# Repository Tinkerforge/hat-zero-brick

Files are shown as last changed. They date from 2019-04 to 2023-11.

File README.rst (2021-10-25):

HAT Zero Brick
==============

This repository contains the firmware source code and the hardware design
files. The documentation generator configs can be found at
https://github.com/Tinkerforge/generators

Repository Content
------------------

software/:
 * examples/: Examples for all supported languages
 * build/: Compiled files
 * src/: Source code of firmware
 * Makefile: Makefile to build project

hardware/:
 * Contains KiCad project files and additionally schematics as PDF

datasheets/:
 * Contains datasheets for sensors and complex ICs that are used

Hardware
--------

The hardware is designed with the open source EDA Suite KiCad
(http://www.kicad.org). Before you are able to open the files,
you have to install the Tinkerforge kicad-libraries
(https://github.com/Tinkerforge/kicad-libraries). You can either clone
them directly in hardware/ or clone them in a separate folder and
symlink them into hardware/
(ln -s kicad_path/kicad-libraries project_path/hardware). After that you
can open the .pro file in hardware/ with KiCad and from there view and
modify the schematics and the PCB layout.

Software
--------

If you want to do your own Brick/Bricklet firmware development we highly
recommend that you use our build environment setup script and read the
tutorial (https://www.tinkerforge.com/en/doc/Tutorials/Tutorial_Build_Environment/Tutorial.html).

To compile the C code we recommend you to install the newest GNU Arm Embedded
Toolchain (https://launchpad.net/gcc-arm-embedded/+download).
You also need to install bricklib2 (https://github.com/Tinkerforge/bricklib2).

You can either clone it directly in software/src/ or clone it in a
separate folder and symlink it into software/src/
(ln -s bricklib_path/bricklib2 project_path/software/src/). Finally make sure to
have CMake installed (http://www.cmake.org/cmake/resources/software.html).

After that you can build the firmware by invoking make in software/.
The firmware (.zbin) can then be found in software/build/ and uploaded
with brickv (click button "Flashing" on start screen).

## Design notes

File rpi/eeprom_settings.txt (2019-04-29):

########################################################################
# EEPROM settings text file
#
# Edit this file for your particular board and run through eepmake tool,
# then use eepflash tool to write to attached HAT ID EEPROM 
#
# Tools available:
#  eepmake   Parses EEPROM text file and creates binary .eep file
#  eepdump   Dumps a binary .eep file as human readable text (for debug)
#  eepflash  Write or read .eep binary image to/from HAT EEPROM
#
########################################################################

########################################################################
# Vendor info

# 128 bit UUID. If left at zero eepmake tool will auto-generate
# RFC 4122 compliant UUID
product_uuid b7603365-412f-47ef-a4d2-e60170d12fc1

# 16 bit product id (2126)
product_id 0x085D

# 16 bit product version
product_ver 0x001

# ASCII vendor string  (max 255 characters)
vendor "Tinkerforge GmbH"

# ASCII product string (max 255 characters)
product "HAT Zero Brick"

########################################################################
# GPIO bank settings, set to nonzero to change from the default.
# NOTE these setting can only be set per BANK, uncommenting any of
# these will force the bank to use the custom setting.

# drive strength, 0=default, 1-8=2,4,6,8,10,12,14,16mA, 9-15=reserved
gpio_drive 0

# 0=default, 1=slew rate limiting, 2=no slew limiting, 3=reserved
gpio_slew 0

# 0=default, 1=hysteresis disabled, 2=hysteresis enabled, 3=reserved
gpio_hysteresis 0

# If board back-powers Pi via 5V GPIO header pins:
# 0 = board does not back-power
# 1 = board back-powers and can supply the Pi with a minimum of 1.3A
# 2 = board back-powers and can supply the Pi with a minimum of 2A
# 3 = reserved
# If back_power=2 then USB high current mode will be automatically 
# enabled on the Pi
back_power 1

########################################################################
# GPIO pins, uncomment for GPIOs used on board
# Options for FUNCTION: INPUT, OUTPUT, ALT0-ALT5
# Options for PULL: DEFAULT, UP, DOWN, NONE
# NB GPIO0 and GPIO1 are reserved for ID EEPROM so cannot be set

#         GPIO  FUNCTION  PULL
#         ----  --------  ----
#setgpio  2     INPUT     DEFAULT
#setgpio  3     INPUT     DEFAULT
#setgpio  4     INPUT     DEFAULT
#setgpio  5     INPUT     DEFAULT
#setgpio  6     INPUT     DEFAULT
#setgpio  7     INPUT     DEFAULT
#setgpio  8     INPUT     DEFAULT
#setgpio  9     INPUT     DEFAULT
#setgpio  10    INPUT     DEFAULT
#setgpio  11    INPUT     DEFAULT
#setgpio  12    INPUT     DEFAULT
#setgpio  13    INPUT     DEFAULT
#setgpio  14    INPUT     DEFAULT
#setgpio  15    INPUT     DEFAULT
#setgpio  16    INPUT     DEFAULT
#setgpio  17    INPUT     DEFAULT
#setgpio  18    INPUT     DEFAULT
#setgpio  19    INPUT     DEFAULT
#setgpio  20    INPUT     DEFAULT
#setgpio  21    INPUT     DEFAULT
setgpio  22    OUTPUT     UP           # Chip Select
setgpio  23    OUTPUT     UP           # Chip Select
setgpio  24    OUTPUT     UP           # Chip Select
setgpio  25    OUTPUT     UP           # Chip Select
#setgpio  26    INPUT     DEFAULT
setgpio  27    OUTPUT     UP           # Chip Select

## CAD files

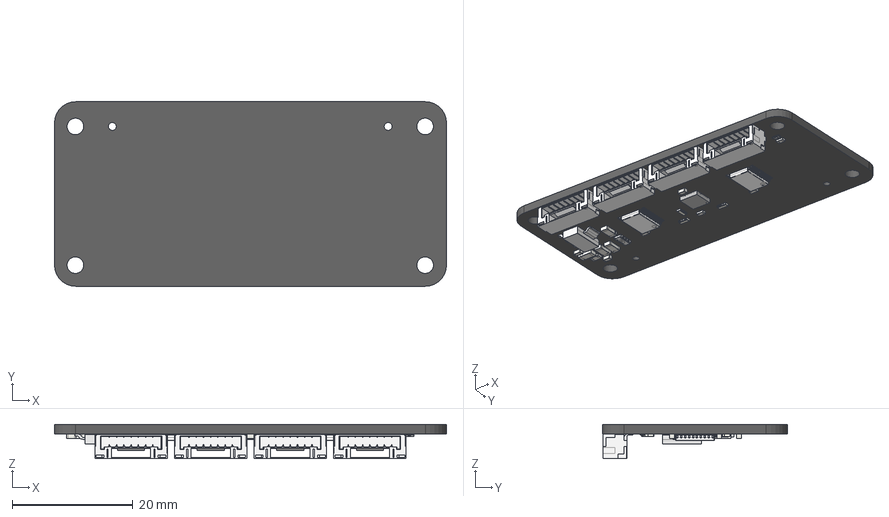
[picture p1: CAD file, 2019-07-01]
hardware/hat-zero.FCStd
65.0 x 30.6 x 5.70 mm
Pcb
U202_TSSOP-20_5B6C4061
CP203_Cut_5B6C3E7D
C101_C_0603_5C90B1AD
C102_C_1206_5B6C3E07
C103_C_1206_5B6C3E11
C104_C_0603_5B6C3E1B
C105_C_1206_5B6C3E25
C106_C_0603_5B6C3E2F
C107_C_1206_5B6C3E39
C201_C_0603_5B6C3E43
C202_C_0603_5B6C3E4D
CP201_Cut_5B6C3E5D
CP202_Cut_5B6C3E6D
CP204_Cut_5B6C3E8D
D101_D_0603_blue_5B6C3E9E
L101_R_0805_5B6C3EEF
P201_BrickletConn_7pin_5B6C3F07
P202_BrickletConn_7pin_5B6C3F1A
P203_BrickletConn_7pin_5B6C3F2D
P204_BrickletConn_7pin_5B6C3F40
R101_R_0603_5B6C3F4A
RP102_R_4x0603_5B6C3F6A
RP103_Cut_5C90B573
RP104_Cut_5B6C3F8A
RP106_Cut_5B6C3FAA
RP201_Cut_5B6C3FBA
RP202_Cut_5B6C3FCA
RP203_Cut_5B6C3FDA
RP204_Cut_5B6C3FEA
U101_QFN-24_4x4mm_Pitch0.5mm_5B6C400F
U102_SOT-223_5B6C4027
U201_TSSOP-20_5B6C4044
R102_R_0603_5B70EDAA
R1_R_0402_5C9144F8
R2_R_0402_5C914B40
R3_R_0402_5C914B4A
R4_R_0402_5C914B54

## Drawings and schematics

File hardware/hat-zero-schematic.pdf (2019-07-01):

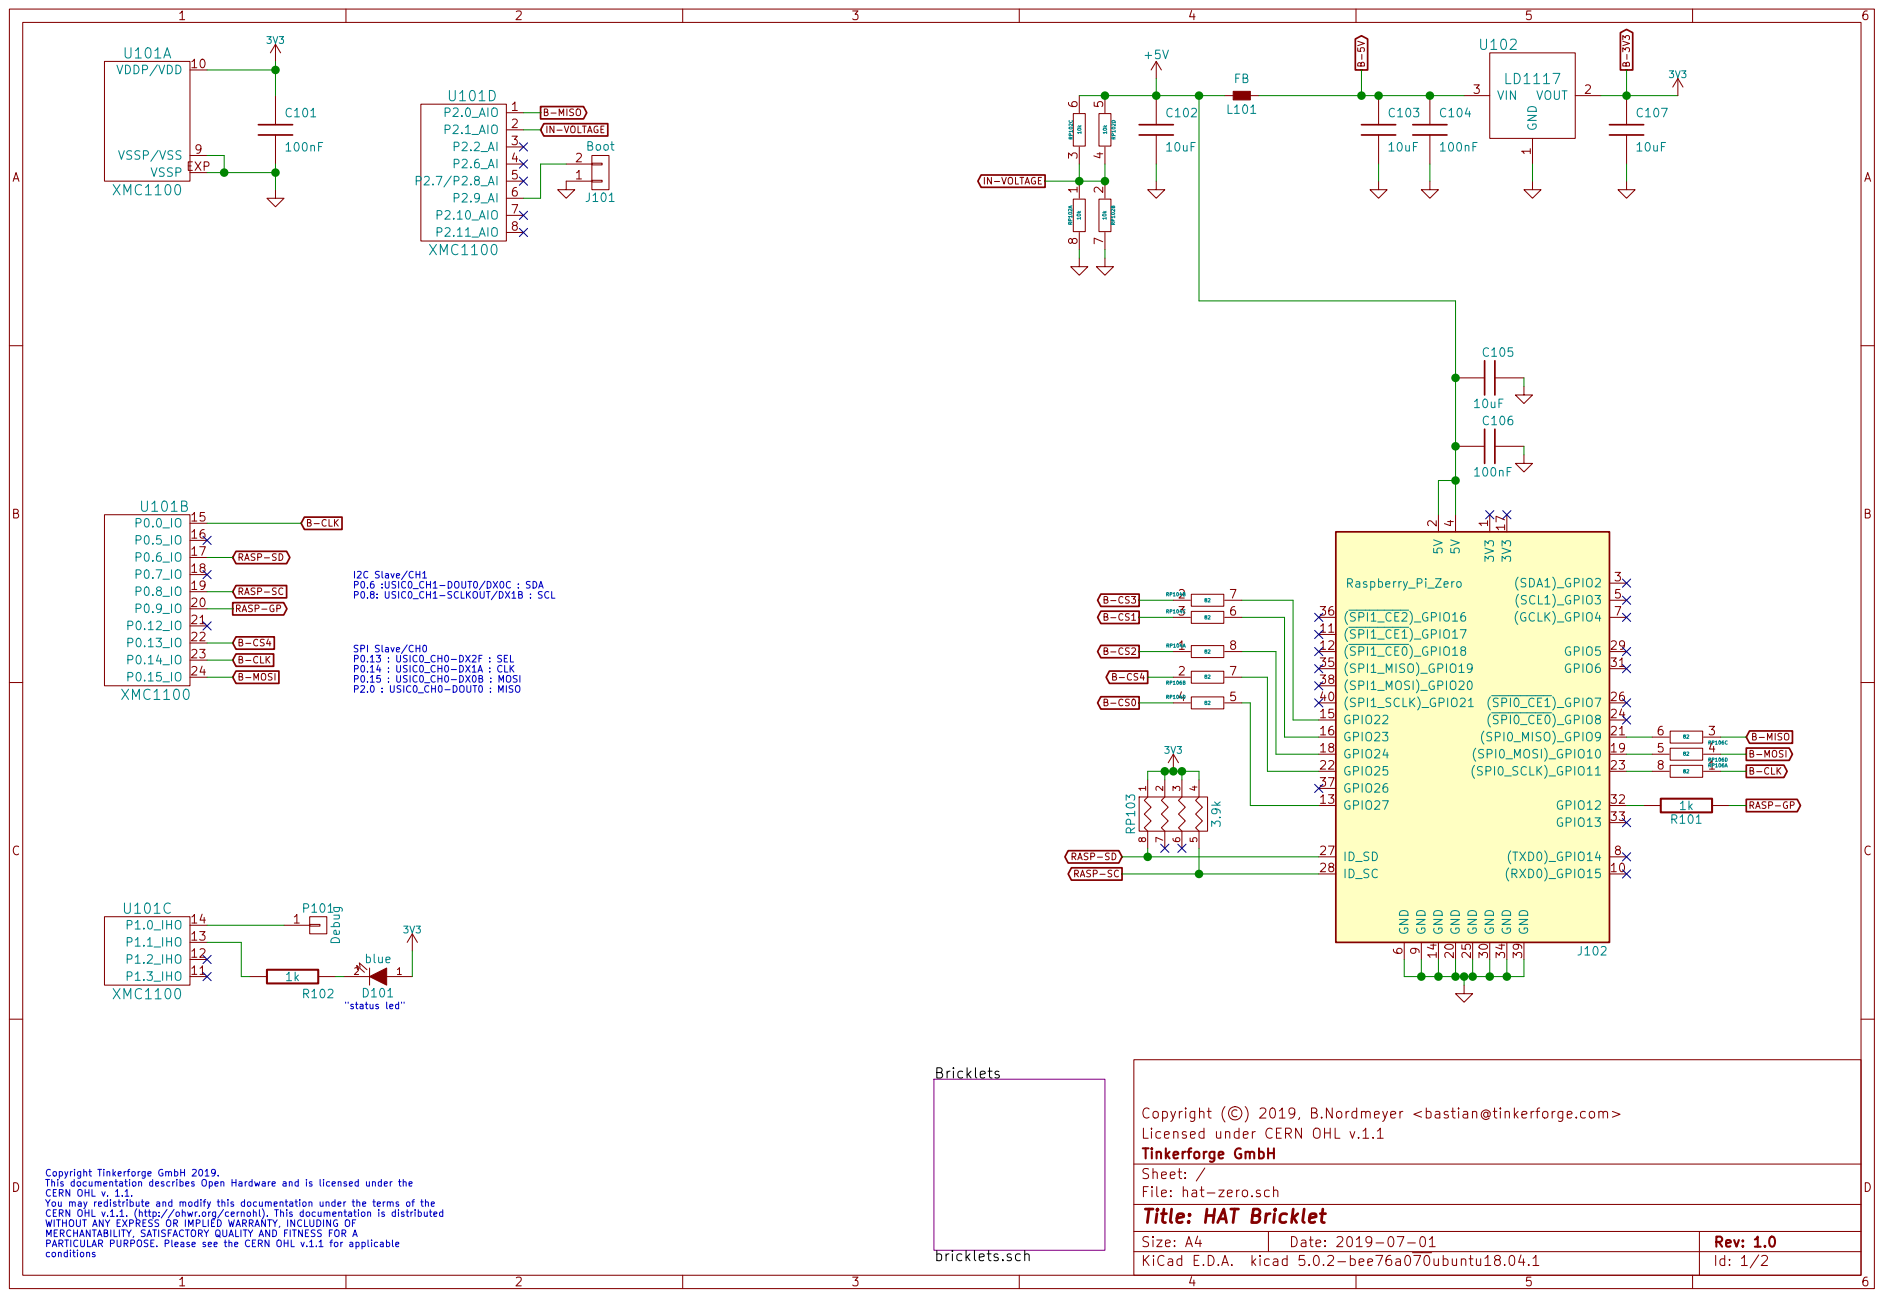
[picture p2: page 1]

B-MOSI B-MISO B-5V RASP-SC

1k SPI Slave/CH0 P0.13 : USIC0_CH0-DX2F : SEL P0.14 : USIC0_CH0-DX1A : CLK

Licensed under CERN OHL v.1.1 Copyright (©) 2019, B.Nordmeyer <bastian@tinkerforge.com>

Id: 1/2 Title: HAT Bricklet File: hat-zero.sch Sheet: / Tinkerforge GmbH

PARTICULAR PURPOSE. Please see the CERN OHL v.1.1 for applicable
conditions

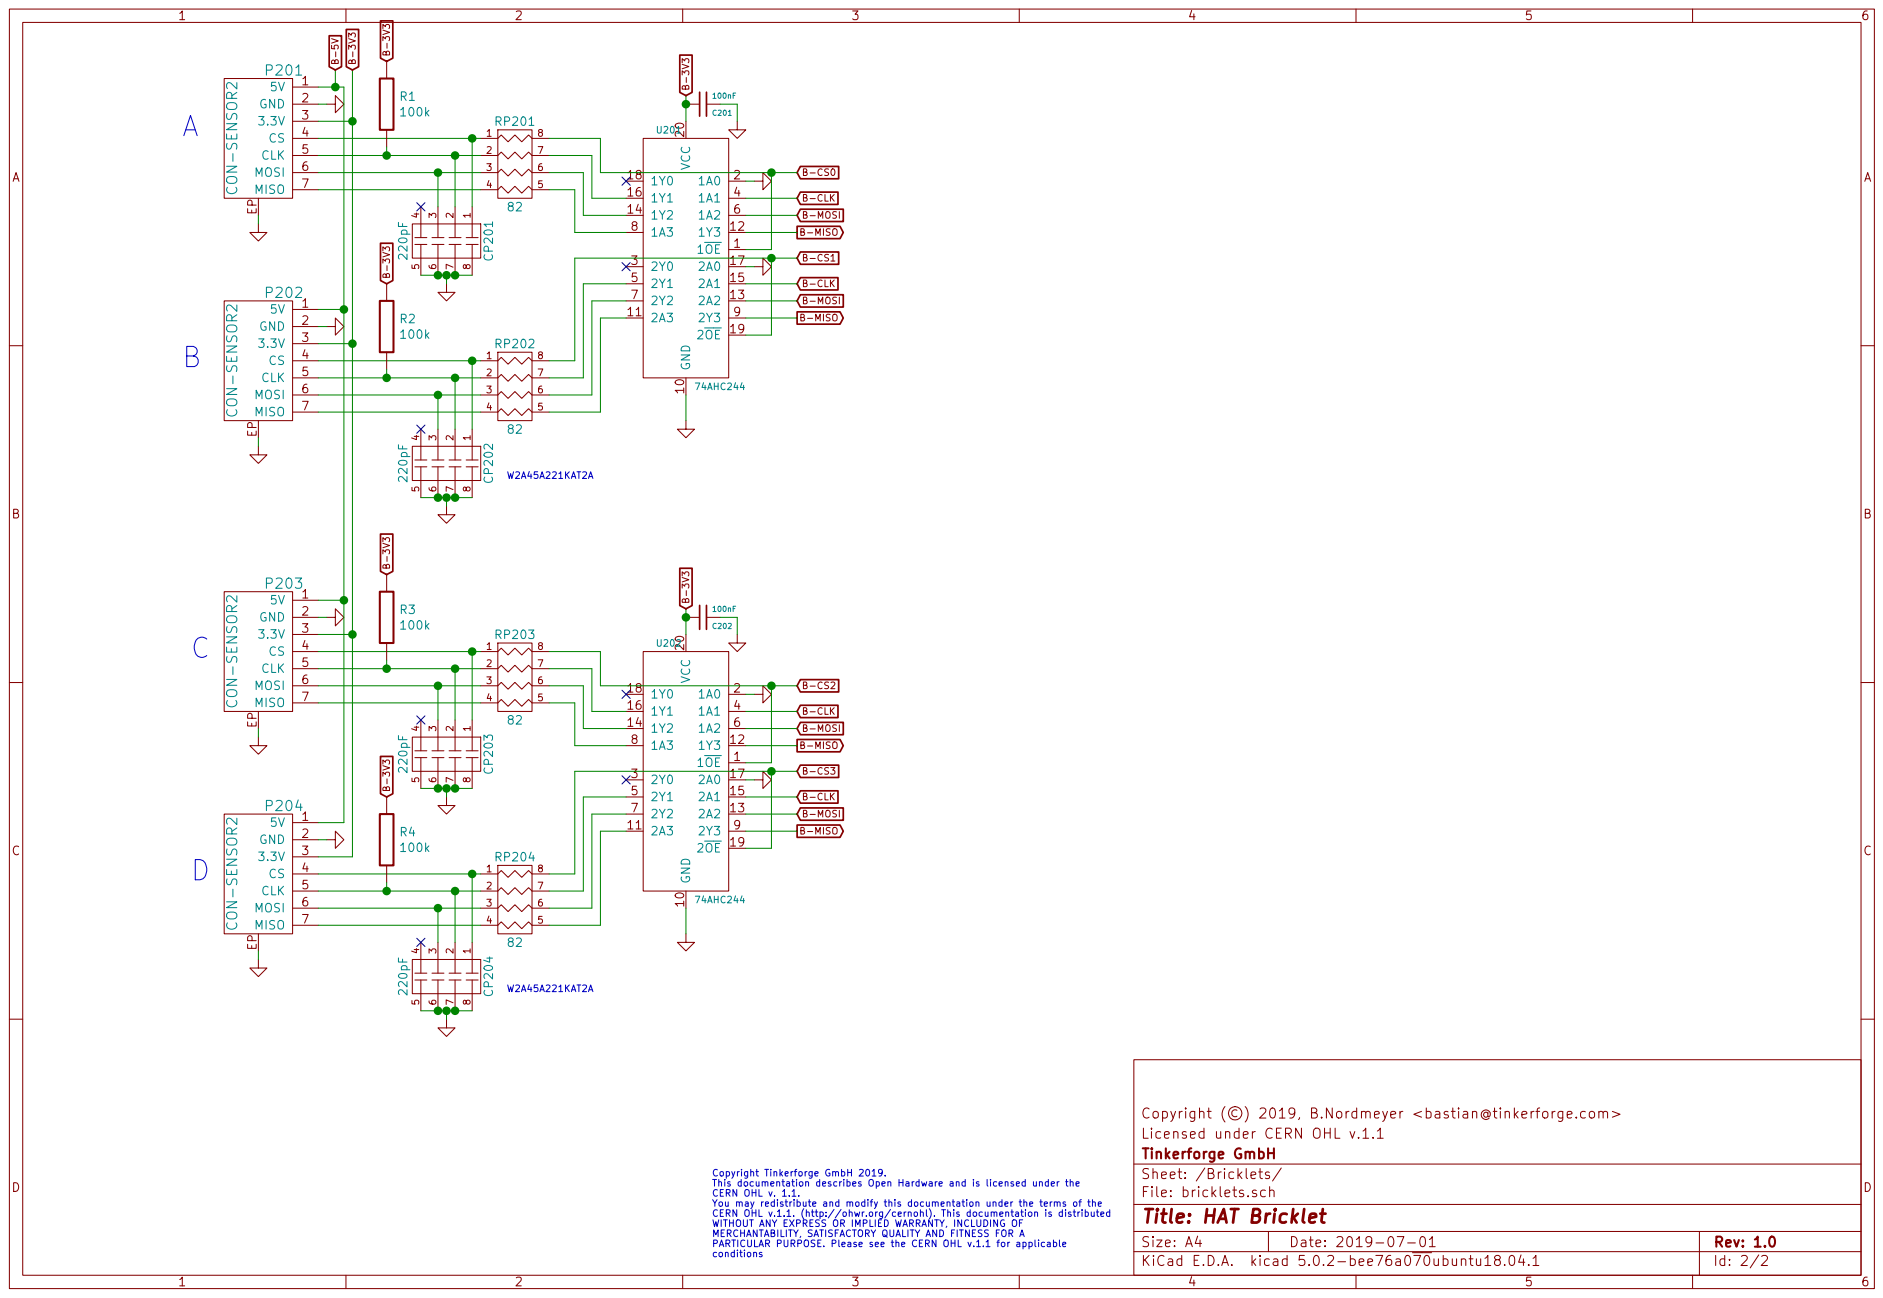
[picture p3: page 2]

Licensed under CERN OHL v.1.1 Copyright (©) 2019, B.Nordmeyer <bastian@tinkerforge.com>

Id: 2/2 Title: HAT Bricklet File: bricklets.sch Sheet: /Bricklets/ Tinkerforge GmbH

PARTICULAR PURPOSE. Please see the CERN OHL v.1.1 for applicable

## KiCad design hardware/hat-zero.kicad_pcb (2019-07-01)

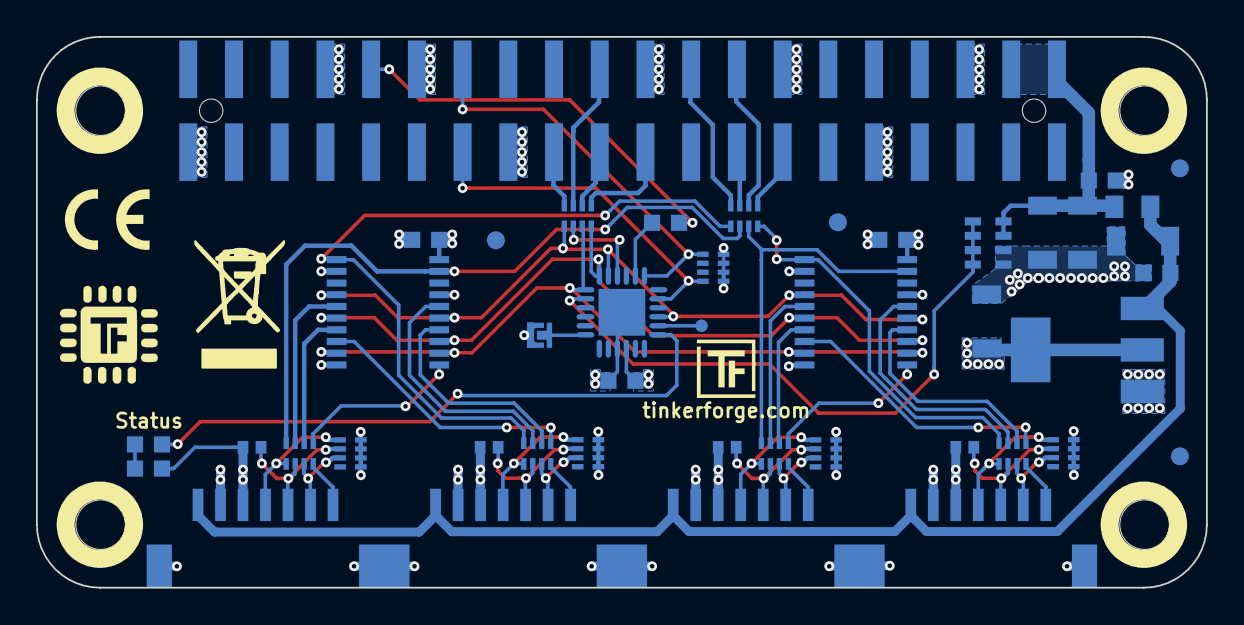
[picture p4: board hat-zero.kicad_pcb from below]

Board: 4 copper layers, 65.0 x 30.6 mm, 46 parts (42 on the bottom side), 57 nets.

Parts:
C101, C104, C106, C201, C202: 100nF; C0603F
C102, C103, C105, C107: 10uF; C1206
CP201, CP202, CP203, CP204: 220pF; 4X0402
D101: blue; D0603F
Fiducial_Mark: VAL**; Fiducial_Mark
Fiducial_Mark#2, Fiducial_Mark#3, Fiducial_Mark#4: VAL**; Fiducial_Mark
J101: Boot; SolderJumper
J102: Raspberry_Pi_Zero; raspberrypi_zero_hat
L101: FB; R0805
P101: Debug; DEBUG_PAD
P201, P202, P203, P204: CON-SENSOR2
R1, R2, R3, R4: 100k; R0402F
R101, R102: 1k; R0603F
RP102: 10k; 4X0603
RP103: 3.9k; 4X0402
RP104, RP106, RP201, RP202, RP203, RP204: 82; 4X0402
U101: XMC1100; QFN24-4x4mm-0.5mm
U102: LD1117; SOT-223
U201, U202: 74AHC244; TSSOP20
VAL: CE_5mm
VAL#2: WEEE_7mm

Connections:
+5V: C102.1, C105.2, C106.2, J102.2, J102.4, L101.2, RP102.5, RP102.6
B-3V3: C101.1, C107.1, C201.2, C202.2, D101.1, P201.3, P202.3, P203.3, P204.3, R1.1, R2.1, R3.1, R4.1, RP103.1, RP103.2, RP103.3, RP103.4, U101.10, U102.2, U201.20, U202.20
B-5V: C103.1, C104.1, L101.1, P201.1, P202.1, P203.1, P204.1, U102.3
B-CLK: RP106.1, U101.15, U101.23, U201.4, U201.15, U202.4, U202.15
B-CS0: RP104.4, RP201.8, U201.1
B-CS1: RP104.3, RP202.8, U201.19
B-CS2: RP104.1, RP203.8, U202.1
B-CS3: RP104.2, RP204.8, U202.19
B-CS4: RP106.2, U101.22
B-MISO: RP106.3, U101.1, U201.9, U201.12, U202.9, U202.12
B-MOSI: RP106.4, U101.24, U201.6, U201.13, U202.6, U202.13
GND: C101.2, C102.2, C103.2, C104.2, C105.1, C106.1, C107.2, C201.1, C202.1, CP201.5, CP201.6, CP201.7, CP201.8, CP202.5, CP202.6, CP202.7, CP202.8, CP203.5, CP203.6, CP203.7, CP203.8, CP204.5, CP204.6, CP204.7, CP204.8, J101.1, J102.6, J102.9, J102.14, J102.20, J102.25, J102.30, J102.34, J102.39, P201.2, P201.EP, P202.2, P202.EP, P203.2, P203.EP, P204.2, P204.EP, RP102.7, RP102.8, U101.9, U101.EXP, U102.1, U201.2, U201.10, U201.17, U202.2, U202.10, U202.17
IN-VOLTAGE: RP102.1, RP102.2, RP102.3, RP102.4, U101.2
unnamed: CP201.1, P201.4, RP201.1
unnamed: CP201.2, P201.5, R1.2, RP201.2
unnamed: CP201.3, P201.6, RP201.3
unnamed: CP202.1, P202.4, RP202.1
unnamed: CP202.2, P202.5, R2.2, RP202.2
unnamed: CP202.3, P202.6, RP202.3
unnamed: CP203.1, P203.4, RP203.1
unnamed: CP203.2, P203.5, R3.2, RP203.2
unnamed: CP203.3, P203.6, RP203.3
unnamed: CP204.1, P204.4, RP204.1
unnamed: CP204.2, P204.5, R4.2, RP204.2
unnamed: CP204.3, P204.6, RP204.3
unnamed: D101.2, R102.1
unnamed: J101.2, U101.6
unnamed: J102.13, RP104.5
unnamed: J102.15, RP104.7
unnamed: J102.16, RP104.6
unnamed: J102.18, RP104.8
unnamed: J102.19, RP106.5
unnamed: J102.21, RP106.6
unnamed: J102.22, RP106.7
unnamed: J102.23, RP106.8
unnamed: J102.32, R101.2
unnamed: P101.1, U101.14
unnamed: P201.7, RP201.4
unnamed: P202.7, RP202.4
unnamed: P203.7, RP203.4
unnamed: P204.7, RP204.4
unnamed: R102.2, U101.13
unnamed: RP201.5, U201.8
unnamed: RP201.6, U201.14
unnamed: RP201.7, U201.16
unnamed: RP202.5, U201.11
unnamed: RP202.6, U201.7
unnamed: RP202.7, U201.5
unnamed: RP203.5, U202.8
unnamed: RP203.6, U202.14
unnamed: RP203.7, U202.16
unnamed: RP204.5, U202.11
unnamed: RP204.6, U202.7
unnamed: RP204.7, U202.5
RASP-GP: R101.1, U101.20
RASP-SC: J102.28, RP103.5, U101.19
RASP-SD: J102.27, RP103.8, U101.17

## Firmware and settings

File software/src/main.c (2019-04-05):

/* hat-zero-brick
 * Copyright (C) 2018-2019 Olaf Lüke <olaf@tinkerforge.com>
 *
 * main.c: Initialization for HAT Zero Brick
 *
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
 * You should have received a copy of the GNU Lesser General Public
 * License along with this library; if not, write to the
 * Free Software Foundation, Inc., 59 Temple Place - Suite 330,
 * Boston, MA 02111-1307, USA.
 */

#include <stdio.h>
#include <stdbool.h>

#include "configs/config.h"

#include "bricklib2/bootloader/bootloader.h"
#include "bricklib2/hal/system_timer/system_timer.h"
#include "bricklib2/logging/logging.h"
#include "communication.h"

#include "eeprom.h"
#include "voltage.h"

int main(void) {
	logging_init();
	logd("Start HAT Zero Bricklet\n\r");

	communication_init();
	eeprom_init();
	voltage_init();

	while(true) {
		bootloader_tick();
		communication_tick();
	}
}

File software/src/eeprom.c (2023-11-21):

/* hat-zero-brick
 * Copyright (C) 2018-2019 Olaf Lüke <olaf@tinkerforge.com>
 *
 * eeprom.c: EEPROM Emulation
 *
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
 * You should have received a copy of the GNU Lesser General Public
 * License along with this library; if not, write to the
 * Free Software Foundation, Inc., 59 Temple Place - Suite 330,
 * Boston, MA 02111-1307, USA.
 */

#include "eeprom.h"

#include "bricklib2/logging/logging.h"
#include "configs/config_eeprom.h"

#include "eeprom_data.h"

#include "xmc_scu.h"

typedef enum XMC_I2C_CH_TDF {
	XMC_I2C_CH_TDF_MASTER_SEND         = 0,
	XMC_I2C_CH_TDF_SLAVE_SEND          = 1 << 8,
	XMC_I2C_CH_TDF_MASTER_RECEIVE_ACK  = 2 << 8,
	XMC_I2C_CH_TDF_MASTER_RECEIVE_NACK = 3 << 8,
	XMC_I2C_CH_TDF_MASTER_START        = 4 << 8,
	XMC_I2C_CH_TDF_MASTER_RESTART      = 5 << 8,
	XMC_I2C_CH_TDF_MASTER_STOP         = 6 << 8
} XMC_I2C_CH_TDF_t;

#define EEPROM_REGISTER_MASK 8191

#define eeprom_tx_handler       IRQ_Hdlr_12
#define eeprom_protocol_handler IRQ_Hdlr_11

static volatile uint32_t eeprom_register = 0;

static uint8_t eeprom_register_high_byte = 0;
static bool eeprom_register_high_byte_received = false;

void eeprom_init(void) {
    logd("EEPROM init\n\r");

	XMC_I2C_CH_Stop(EEPROM_I2C);
	const XMC_GPIO_CONFIG_t input_config =  {
		.mode         = XMC_GPIO_MODE_INPUT_TRISTATE,
		.output_level = XMC_GPIO_OUTPUT_LEVEL_HIGH,
	};

	XMC_GPIO_Init(EEPROM_SCL_PIN, &input_config);
	XMC_GPIO_Init(EEPROM_SDA_PIN, &input_config);

	const XMC_I2C_CH_CONFIG_t i2c_slave_config = {
		.baudrate = EEPROM_I2C_BAUDRATE,
		.address  = EEPROM_I2C_ADDRESS
	};

	const XMC_GPIO_CONFIG_t scl_pin_config = {
		.mode         = EEPROM_SCL_PIN_MODE,
		.output_level = XMC_GPIO_OUTPUT_LEVEL_HIGH,
	};

	const XMC_GPIO_CONFIG_t sda_pin_config = {
		.mode         = EEPROM_SDA_PIN_MODE,
		.output_level = XMC_GPIO_OUTPUT_LEVEL_HIGH,
    };

	XMC_I2C_CH_Init(EEPROM_I2C, &i2c_slave_config);

	XMC_I2C_CH_SetInputSource(EEPROM_I2C, EEPROM_SDA_INPUT, EEPROM_SDA_SOURCE);
	XMC_I2C_CH_SetInputSource(EEPROM_I2C, EEPROM_SCL_INPUT, EEPROM_SCL_SOURCE);

	XMC_USIC_CH_TXFIFO_Configure(EEPROM_I2C, EEPROM_TX_FIFO_POINTER, EEPROM_TX_FIFO_SIZE, 8);
	XMC_USIC_CH_TXFIFO_SetInterruptNodePointer(EEPROM_I2C, XMC_USIC_CH_TXFIFO_INTERRUPT_NODE_POINTER_STANDARD, 3);

	XMC_USIC_CH_RXFIFO_Configure(EEPROM_I2C, EEPROM_RX_FIFO_POINTER, EEPROM_RX_FIFO_SIZE, 8);

	XMC_USIC_CH_SetInterruptNodePointer(EEPROM_I2C, XMC_USIC_CH_INTERRUPT_NODE_POINTER_PROTOCOL, 2);
	XMC_I2C_CH_Start(EEPROM_I2C);

	XMC_GPIO_Init(EEPROM_SCL_PIN, &scl_pin_config);
	XMC_GPIO_Init(EEPROM_SDA_PIN, &sda_pin_config);

	NVIC_SetPriority(12, 1); // tx
	NVIC_EnableIRQ(12);
	NVIC_SetPriority(11, 0); // protocol
	NVIC_EnableIRQ(11);
	XMC_I2C_CH_EnableEvent(EEPROM_I2C, XMC_I2C_CH_EVENT_SLAVE_READ_REQUEST | XMC_I2C_CH_EVENT_ERROR);
}


void __attribute__((optimize("-O3"))) __attribute__ ((section (".ram_code"))) eeprom_tx_handler(void) {
	// Fill fifo (if the read transfer stops we flush the fifo again)
	while(!XMC_USIC_CH_TXFIFO_IsFull(EEPROM_I2C)) {
		EEPROM_I2C->IN[0] = XMC_I2C_CH_TDF_SLAVE_SEND | eeprom_data[eeprom_register];
		eeprom_register = (eeprom_register + 1) & EEPROM_REGISTER_MASK;
	}
}

void __attribute__((optimize("-O3"))) __attribute__ ((section (".ram_code"))) eeprom_protocol_handler(void) {
    uint32_t status = XMC_I2C_CH_GetStatusFlag(EEPROM_I2C);

	// In case of stop condition or error we reset the tx fifo and i2c state machine
	if(status & (XMC_I2C_CH_STATUS_FLAG_ERROR | XMC_I2C_CH_STATUS_FLAG_STOP_CONDITION_RECEIVED)) {
		XMC_USIC_CH_TXFIFO_DisableEvent(EEPROM_I2C, XMC_USIC_CH_TXFIFO_EVENT_CONF_STANDARD);
		XMC_USIC_CH_TXFIFO_ClearEvent(EEPROM_I2C, XMC_USIC_CH_TXFIFO_EVENT_CONF_STANDARD);
		XMC_USIC_CH_TXFIFO_Flush(EEPROM_I2C);
		XMC_USIC_CH_SetTransmitBufferStatus(EEPROM_I2C, 0b10); // Clear bits TDV and TE

		// In case of error we re-initialize the whole thing.
		if(status & XMC_I2C_CH_STATUS_FLAG_ERROR) {
			eeprom_init();
		}

		XMC_I2C_CH_ClearStatusFlag(XMC_I2C0_CH1, XMC_I2C_CH_STATUS_FLAG_ERROR | XMC_I2C_CH_STATUS_FLAG_STOP_CONDITION_RECEIVED);
	}

	if(status & XMC_I2C_CH_STATUS_FLAG_SLAVE_READ_REQUESTED) {
		while(!XMC_USIC_CH_RXFIFO_IsEmpty(EEPROM_I2C)) {
			// In case of a read request we set the register variable to the
			// desired register.
            if(!eeprom_register_high_byte_received) {
                eeprom_register_high_byte = XMC_I2C_CH_GetReceivedData(EEPROM_I2C);
                eeprom_register_high_byte_received = true;
            } else {
			    eeprom_register = ((eeprom_register_high_byte << 8) | XMC_I2C_CH_GetReceivedData(EEPROM_I2C)) & EEPROM_REGISTER_MASK;
                eeprom_register_high_byte_received = false;
                eeprom_register_high_byte = 0;

                // Fill buffer with data starting from address.
				XMC_USIC_CH_TXFIFO_Flush(EEPROM_I2C);
                eeprom_tx_handler();
                XMC_USIC_CH_TXFIFO_ClearEvent(EEPROM_I2C, XMC_USIC_CH_TXFIFO_EVENT_CONF_STANDARD);
                XMC_USIC_CH_TXFIFO_EnableEvent(EEPROM_I2C, XMC_USIC_CH_TXFIFO_EVENT_CONF_STANDARD);
            }

		}

		XMC_I2C_CH_ClearStatusFlag(EEPROM_I2C, XMC_I2C_CH_STATUS_FLAG_SLAVE_READ_REQUESTED);
	}

	// If we receive bytes after the register number we read the data
	// and throw it away (we don't have any writable registers).
	if(status & XMC_I2C_CH_STATUS_FLAG_RECEIVE_INDICATION) {
		while(!XMC_USIC_CH_RXFIFO_IsEmpty(EEPROM_I2C)) {
			uint32_t __attribute__((unused)) _ = XMC_I2C_CH_GetReceivedData(EEPROM_I2C);
		}

		XMC_I2C_CH_ClearStatusFlag(EEPROM_I2C, XMC_I2C_CH_STATUS_FLAG_RECEIVE_INDICATION);
	}
}

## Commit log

2018-08-10 prototype of hat zero bricklet added
    [bricklets.sch, hat-zero.kicad_pcb, hat-zero.sch]
2018-08-24 add sym table and pcb hint
    [hat-zero.kicad_pcb]
2018-09-03 Add auto-generated stub implementation
    [cmake_config_custom.txt]
2018-09-03 Add RPi eeprom device-tree files
2018-09-03 Add USB voltage implementation
2018-09-03 Update .gitignore with generated device-tree files
2018-09-04 fix graphical elements
    [hat-zero.kicad_pcb]
2019-02-07 add hint
    [bricklets.sch, hat-zero.kicad_pcb, hat-zero.sch]
2019-03-19 changed pcb layout to single sided placement, added clock pullup's, changed symlib-table
    [bricklets.sch, hat-zero.kicad_pcb, hat-zero.sch]
2019-03-25 add logo
    [hat-zero.kicad_pcb]
2019-04-03 ordered data
    [hat-zero.kicad_pcb]
2019-04-03 Update led/boot pins
2019-04-05 Use Brick device id (starts with 1)
2019-07-01 add schematic, fix descriptions
    [bricklets.sch, hat-zero.kicad_pcb, hat-zero.sch]
2019-07-01 add 3d data
    [hat-zero.FCStd]
2019-09-12 Add USB voltage callback
2020-09-02 uc: Add example driver note.
2021-10-25 Update KiCad link
    https://www.kicad.org/blog/2021/10/Avoid-links-to-former-kicad-domain/
2023-11-21 Add support for Raspberry Pi 5.
    See https://github.com/Tinkerforge/hat-brick/commit/e4480c7a

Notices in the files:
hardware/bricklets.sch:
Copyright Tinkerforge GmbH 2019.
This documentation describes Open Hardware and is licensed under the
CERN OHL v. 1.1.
